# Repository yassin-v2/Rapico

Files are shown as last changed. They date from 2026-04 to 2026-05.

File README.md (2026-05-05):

<picture>
  <source media="(prefers-color-scheme: dark)" srcset="https://github.com/user-attachments/assets/26227bd9-6ad5-4ce1-84e2-db5a73c75b01">
  <source media="(prefers-color-scheme: light)" srcset="https://github.com/user-attachments/assets/26227bd9-6ad5-4ce1-84e2-db5a73c75b01">
  Rapico logo
</picture>

### A RP2040-based development board with a nRF wireless chip, designed in the Raspberry Pi Pico form factor.

----

PCB Render

---

## Features
- **[RP2040](https://pip-assets.raspberrypi.com/categories/814-rp2040/documents/RP-008371-DS-1-rp2040-datasheet.pdf) MCU** - 32bit dual core ARM Cortex M0+ from Raspberry Pi.
- **[nRF24L01P](https://cdn.sparkfun.com/assets/3/d/8/5/1/nRF24L01P_Product_Specification_1_0.pdf) chip** -  2.4GHz radio transceiver, with a PCB trace antenna.
- **USB C** - for programming and power.
- **Raspberry Pi Pico formfactor** - but less pins; 2x18
- **W25Q128JVPIQ flash storage chip** - 16MB high speed flash storage, intergrated with the RP2040 over quad SPI.
- **I2C and SPI** - on many pins.
- **5V and 3.3V power pins**
- Power indicator LED and another addressable LED

## Pinout

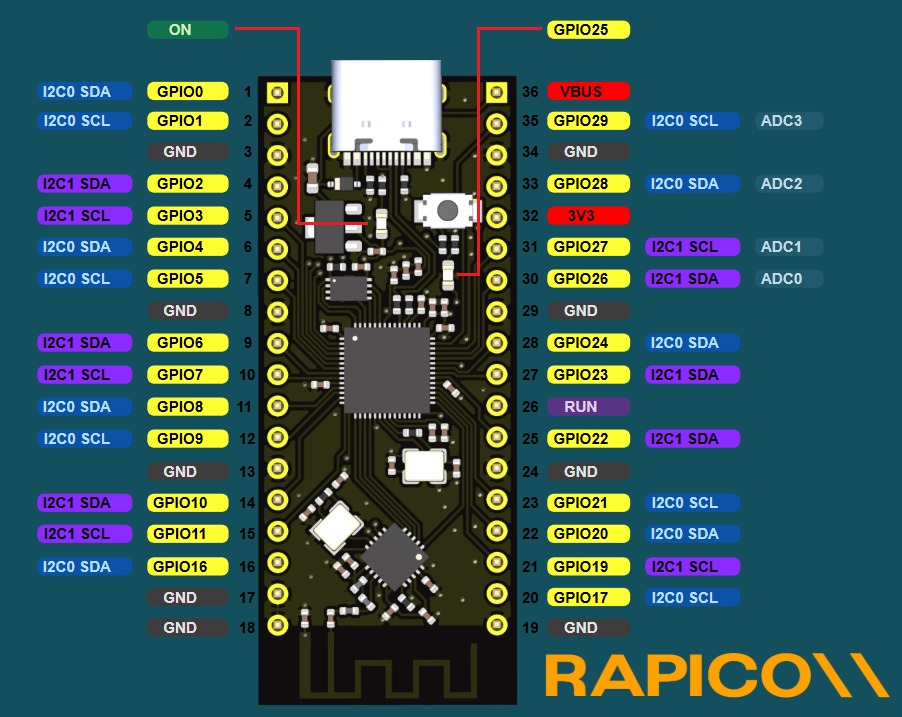
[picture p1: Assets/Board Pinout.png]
PCB Render


## PCB Design
*Find the PCB files [here](https://github.com/yassin-v2/Rapico/tree/main/PCB)*

The PCB is a 2 layer PCB with dimentions 51mm x 21mm.

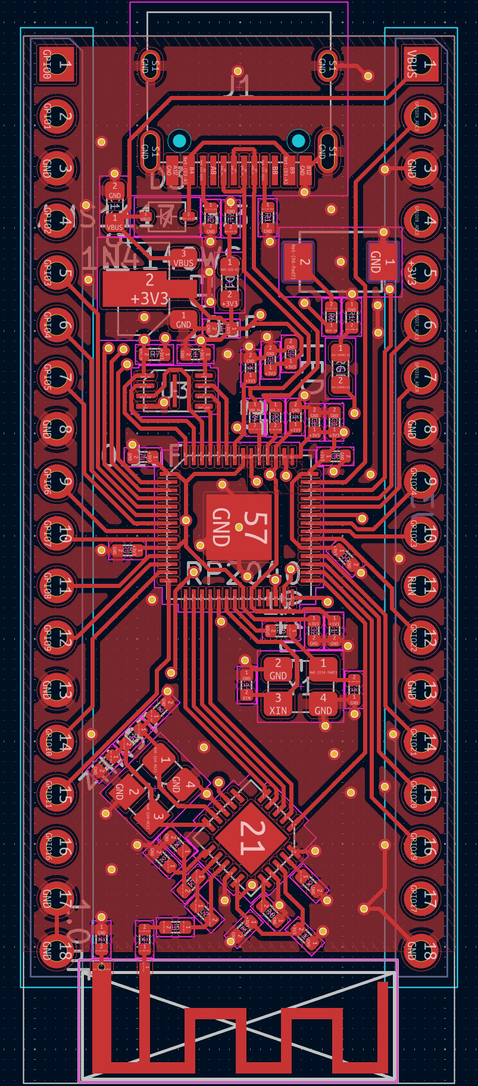
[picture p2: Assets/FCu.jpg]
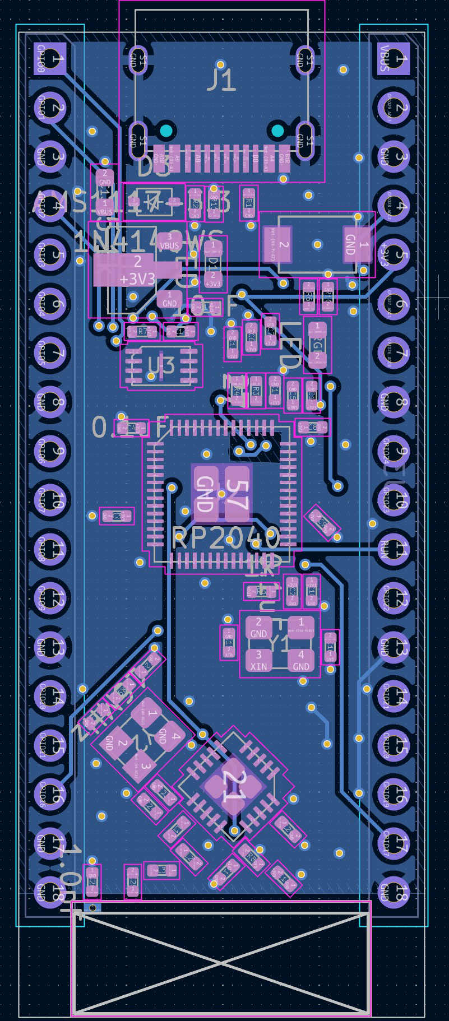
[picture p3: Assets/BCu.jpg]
|  |  |
|:---:|:---:|

## Schematic Design
*Find the schematic files [here](https://github.com/yassin-v2/Rapico/tree/main/PCB)*

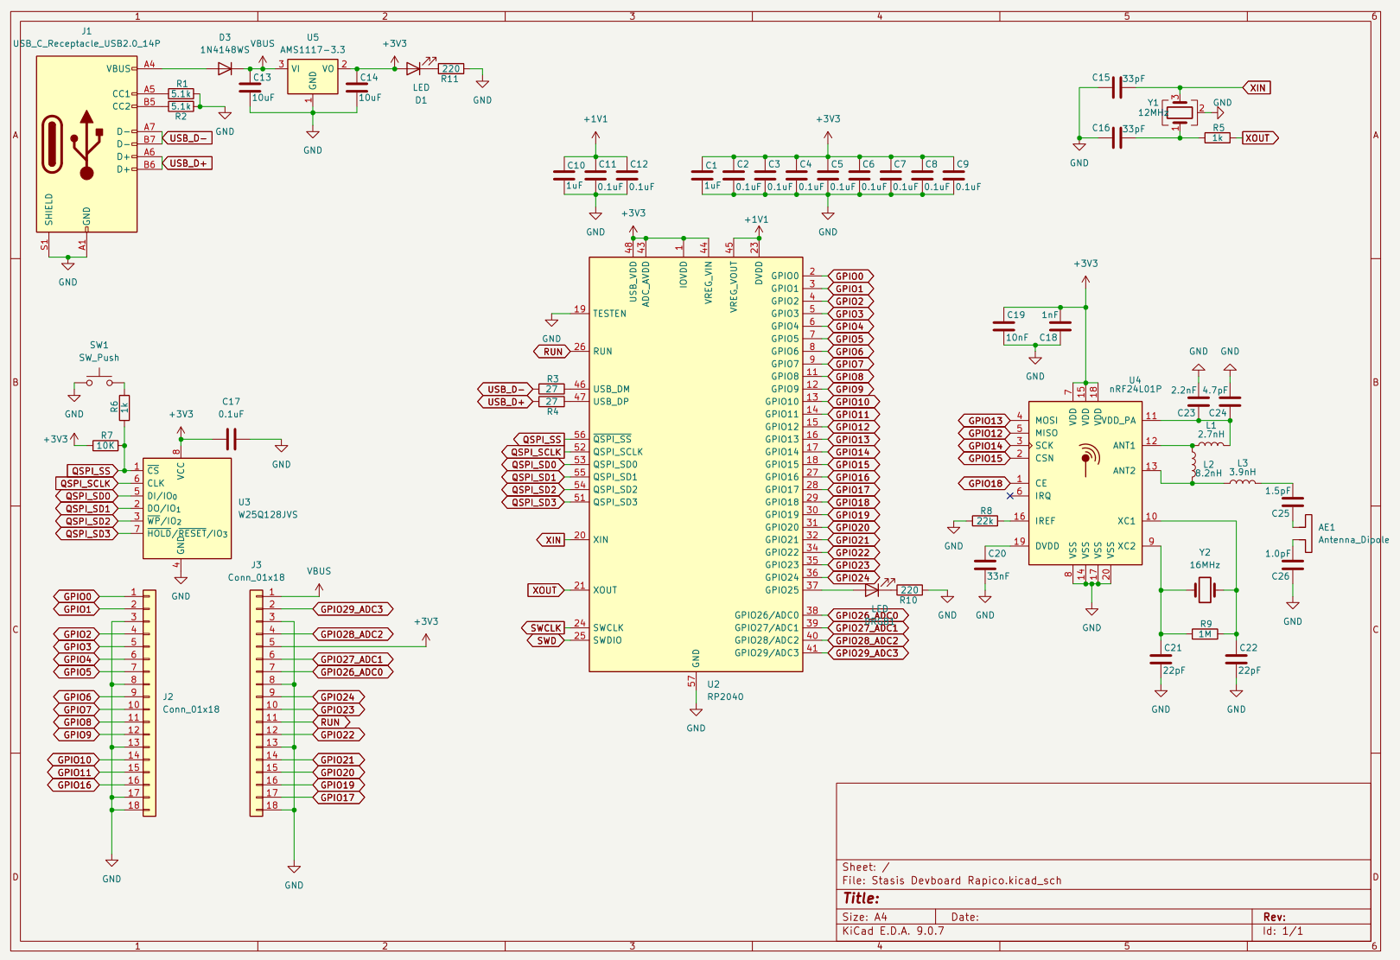
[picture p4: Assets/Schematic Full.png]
  

### nRF chip schematic:
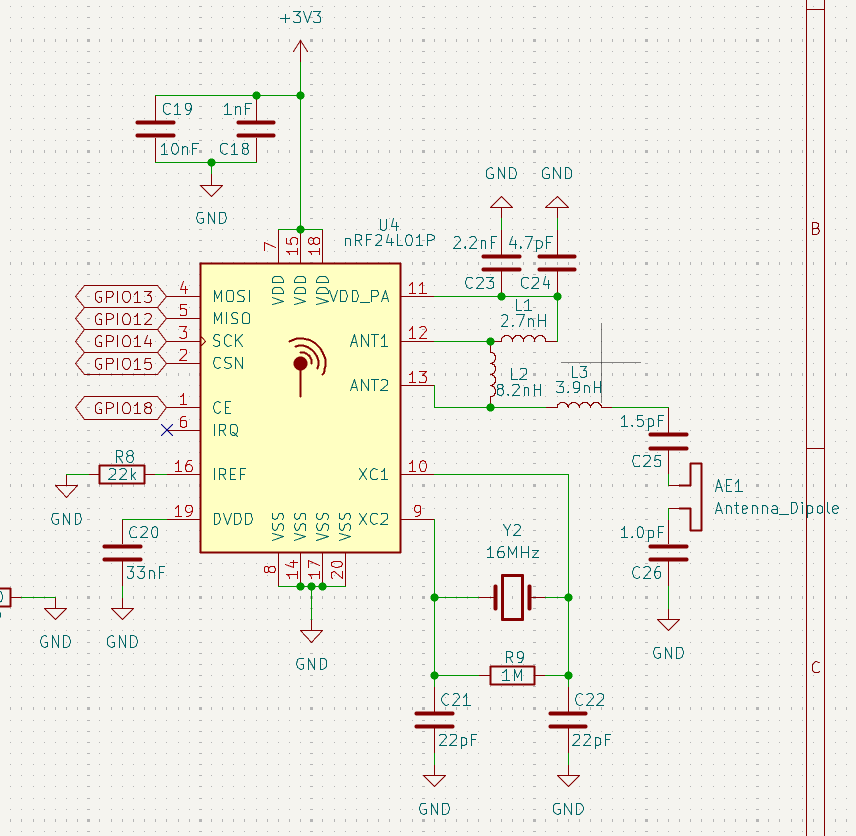
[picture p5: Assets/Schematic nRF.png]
  

### Power input schematic:
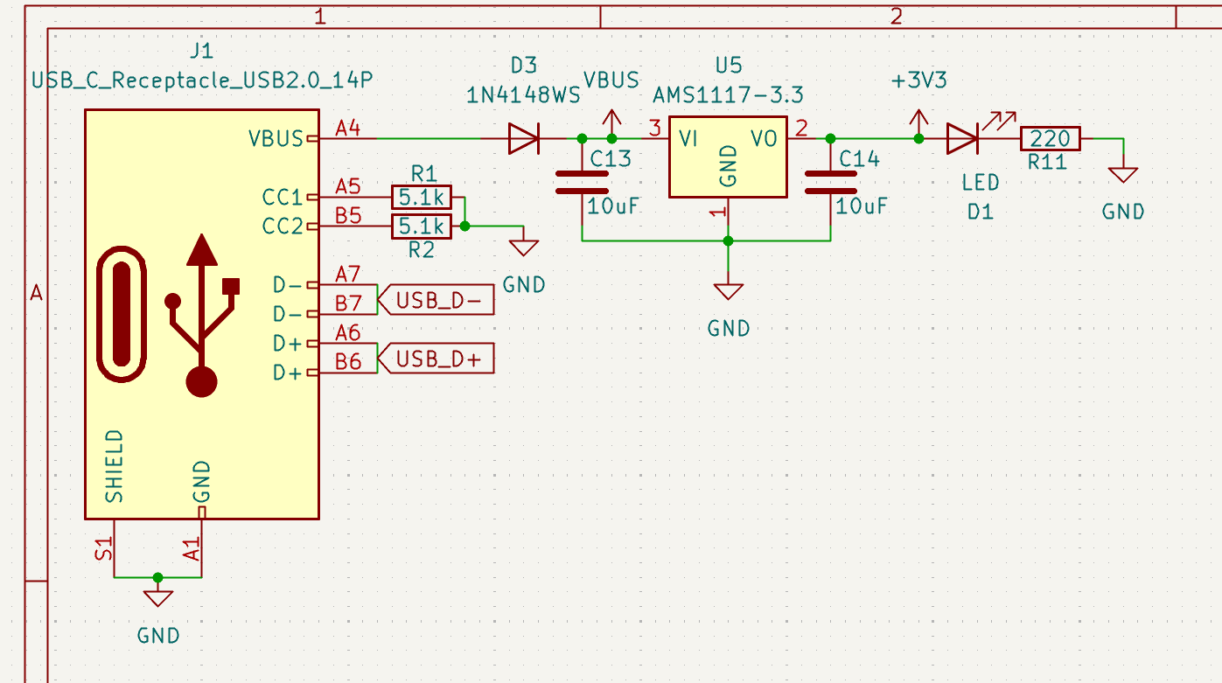
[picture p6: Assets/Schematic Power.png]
  

----
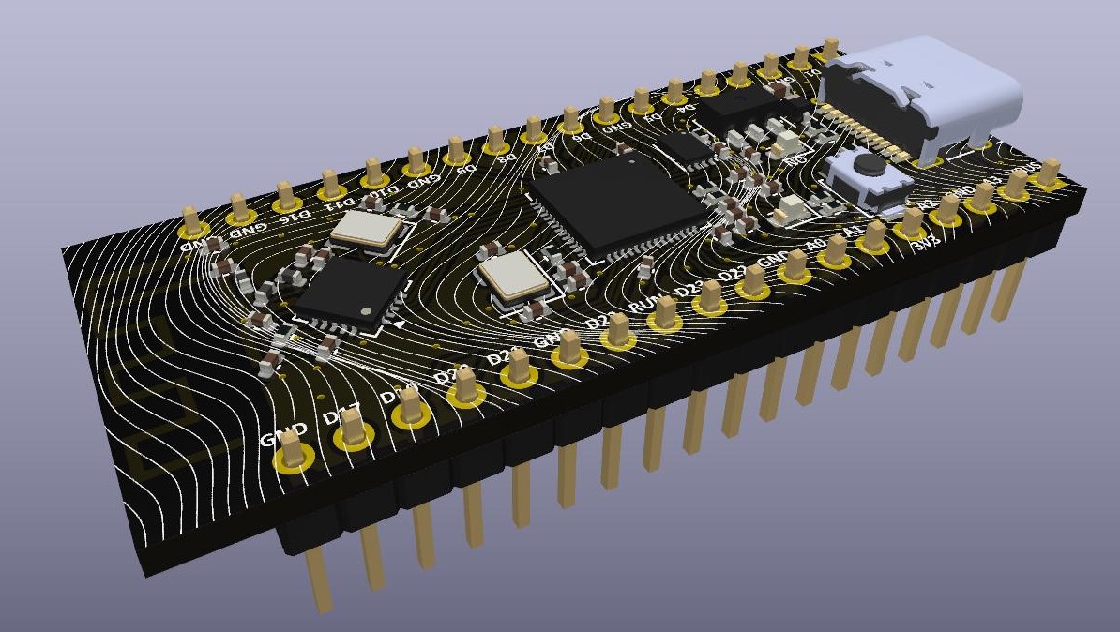
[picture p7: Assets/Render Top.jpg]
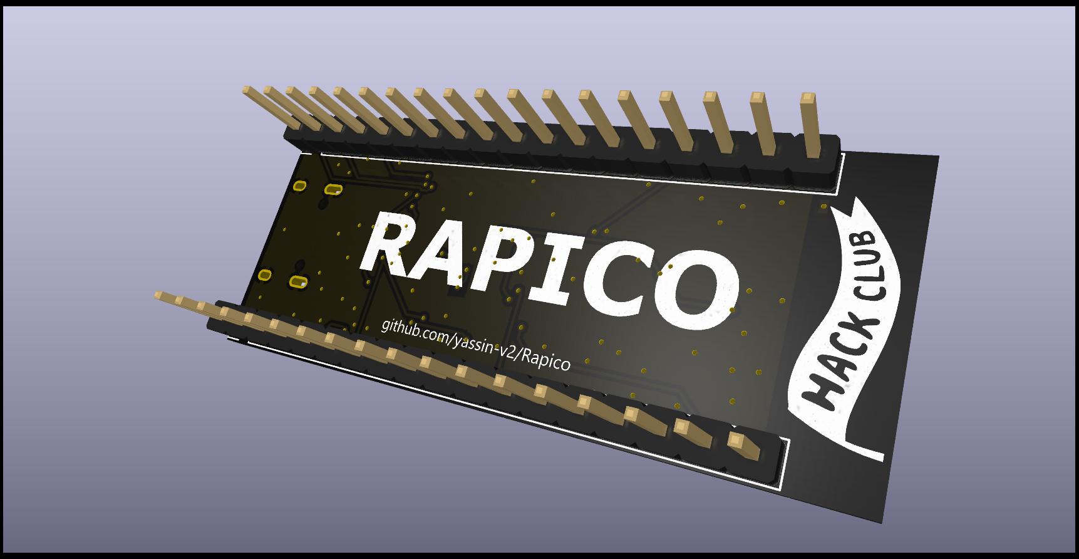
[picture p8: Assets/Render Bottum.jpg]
|  |  |  |
|:---:|:---:|:---:|

<p align="center"><strong><em>Made with KiCad 9, as part of <a href="https://stasis.hackclub.com">Stasis</a> from <a href="https://hackclub.com/">Hackclub</a></em></strong></p>

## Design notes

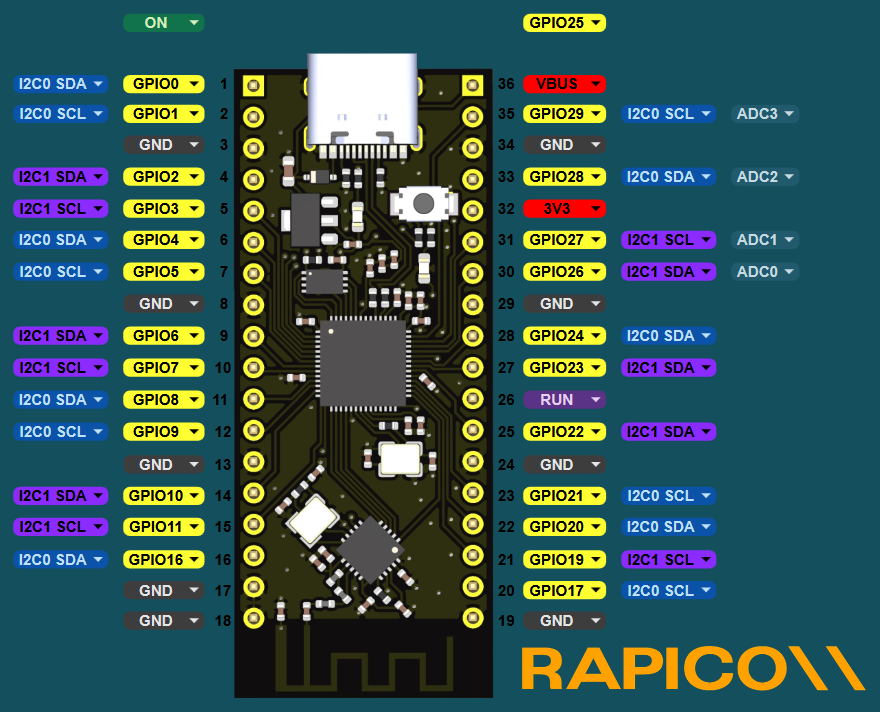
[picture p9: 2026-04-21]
Assets/Board Pinout V2.png

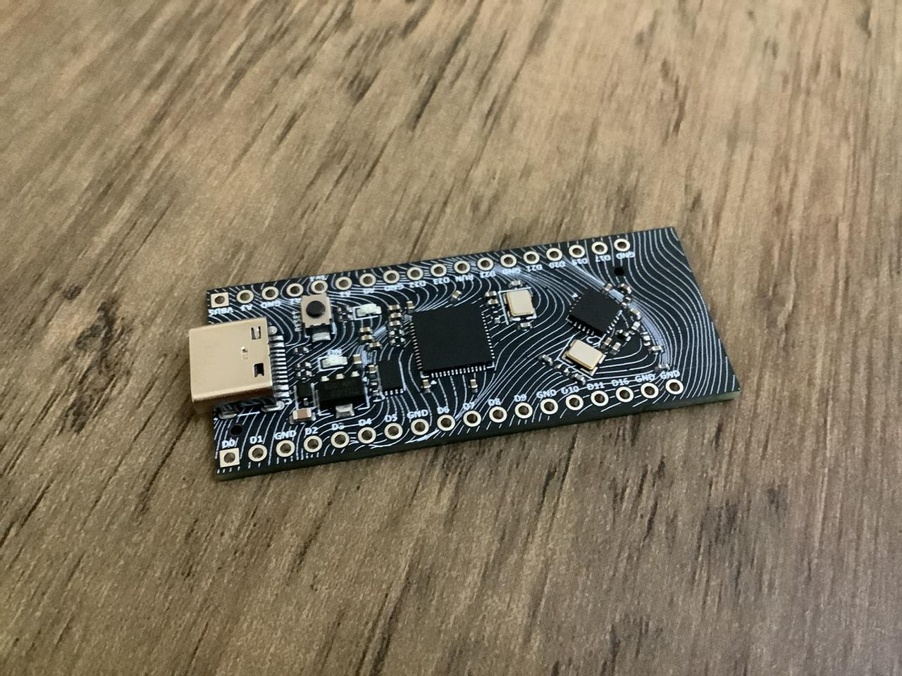
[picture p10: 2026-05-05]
Assets/image.png

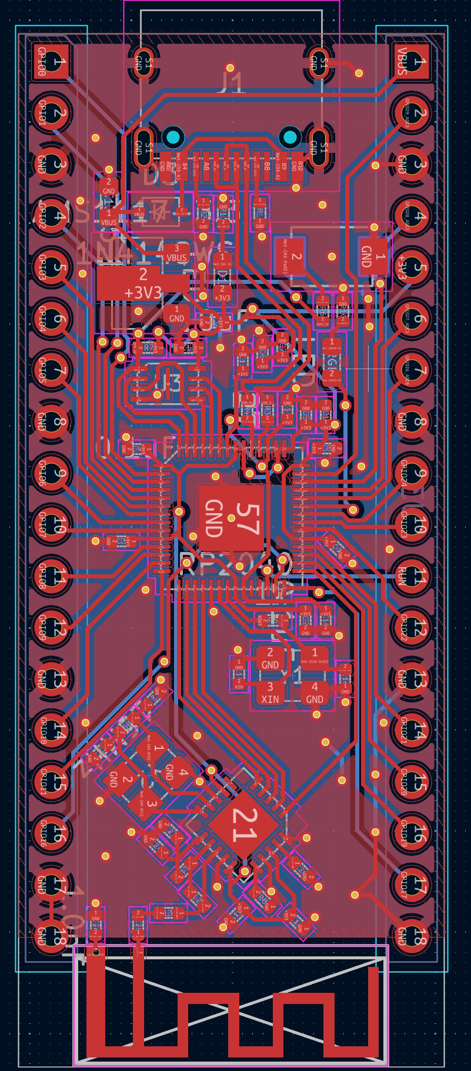
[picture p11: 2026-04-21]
Assets/FCu and BCu.jpg

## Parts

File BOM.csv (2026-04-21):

Comment | Designator | Footprint | JLCPCB Part #
C1,C10 | 1uF | 0402 | C52923
C2,C3 | 0.1uF | 0402 | C307331
C11,C12,C17,C4,C5,C6,C7,C8,C9 | 0.1uF | 0402 | C307331
C13 | 10uF | 0603 | C96446
C14 | 10uF | 0402 | C15525
C15,C16 | 33pF | 0402 | C1562
C18 | 1nF | 0402 | C1523
C19 | 10nF | 0402 | C15195
C20 | 33nF | 0402 | C106862
C21,C22 | 22pF | 0402 | C1555
C23 | 2.2nF | 0402 | C1531
C24 | 4.7pF | 0402 | C1569
C25 | 1.5pF | 0402 | C1552
C26 | 1.0pF | 0402 | C1550
D1,DRGB1 | LED | 0603 | C2286
D3 | 1N4148WS | SOD-323 | C2128
J1 | USB_C_Receptacle_USB2.0_14P | SMD | C165948
L1 | 2.7nH | 0402 | C77108
L2 | 8.2nH | 0402 | C76778
L3 | 3.9nH | 0402 | C76775
R1,R2 | 5.1k | 0402 | C25905
R3,R4 | 27 | 0402 | C25105
R5,R6 | 1k | 0402 | C11702
R7 | 10K | 0402 | C25744
R8 | 22k | 0402 | C25768
R9 | 1M | 0402 | C26083
R10,R11 | 220 | 0402 | C25082
SW1 | SW_Push | SMD,4x3mm | C720477
U2 | RP2040 | LQFN-56(7x7) | C2040
U3 | W25Q128JVS | USON-8-EP(2x3) | C2843335
U4 | nRF24L01P | QFN-20-EP(4x4) | C8791
U5 | AMS1117-3.3 | SOT-89 | C347256
Y1 | 12MHz | SMD3225-4P | C9002
Y2 | 16MHz | SMD3225-4P | C13738

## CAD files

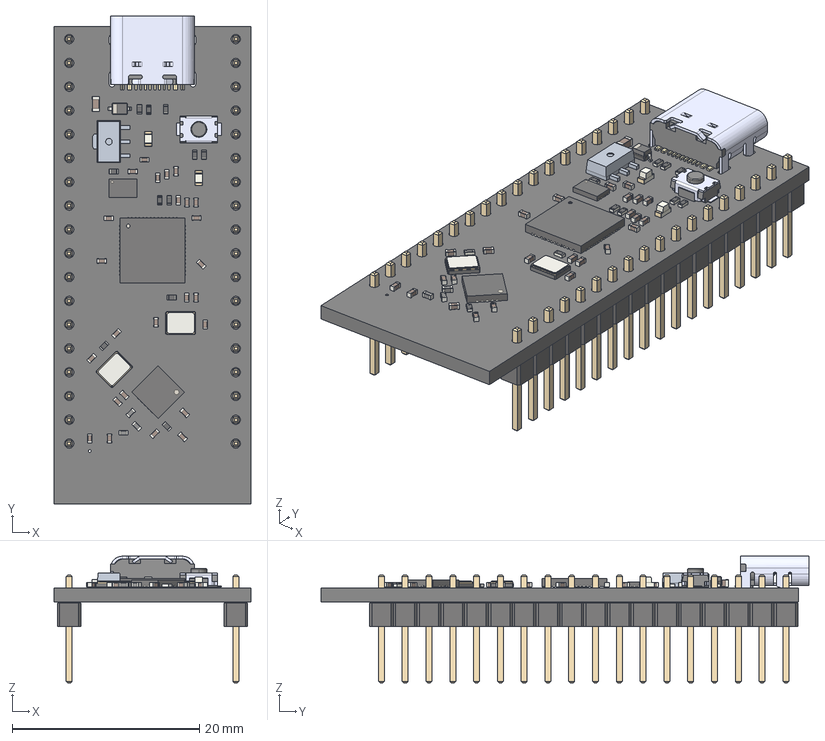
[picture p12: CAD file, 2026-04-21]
PCB/Rapico-Step.step
21.0 x 52.1 x 13.5 mm
Stasis Devboard Rapico 1.1.1
R_0402_1005Metric x 11
C_0603_1608Metric
C_0402_1005Metric x 25
L_0402_1005Metric x 3
QFN-56-1EP_7x7mm_P0.4mm_EP3.2x3.2mm
D_SOD-323
Crystal_SMD_3225-4Pin_3.2x2.5mm x 2
QFN-20-1EP_4x4mm_P0.5mm_EP2.5x2.5mm
Winbond_USON-8-1EP_3x2mm_P0.5mm_EP0.2x1.6mm
LED_0603_1608Metric x 2
TYPE-C-31-M-12
TS-1088-AR02016
PinHeader_1x18_P2.54mm_Vertical x 2
Stasis Devboard Rapico_PCB

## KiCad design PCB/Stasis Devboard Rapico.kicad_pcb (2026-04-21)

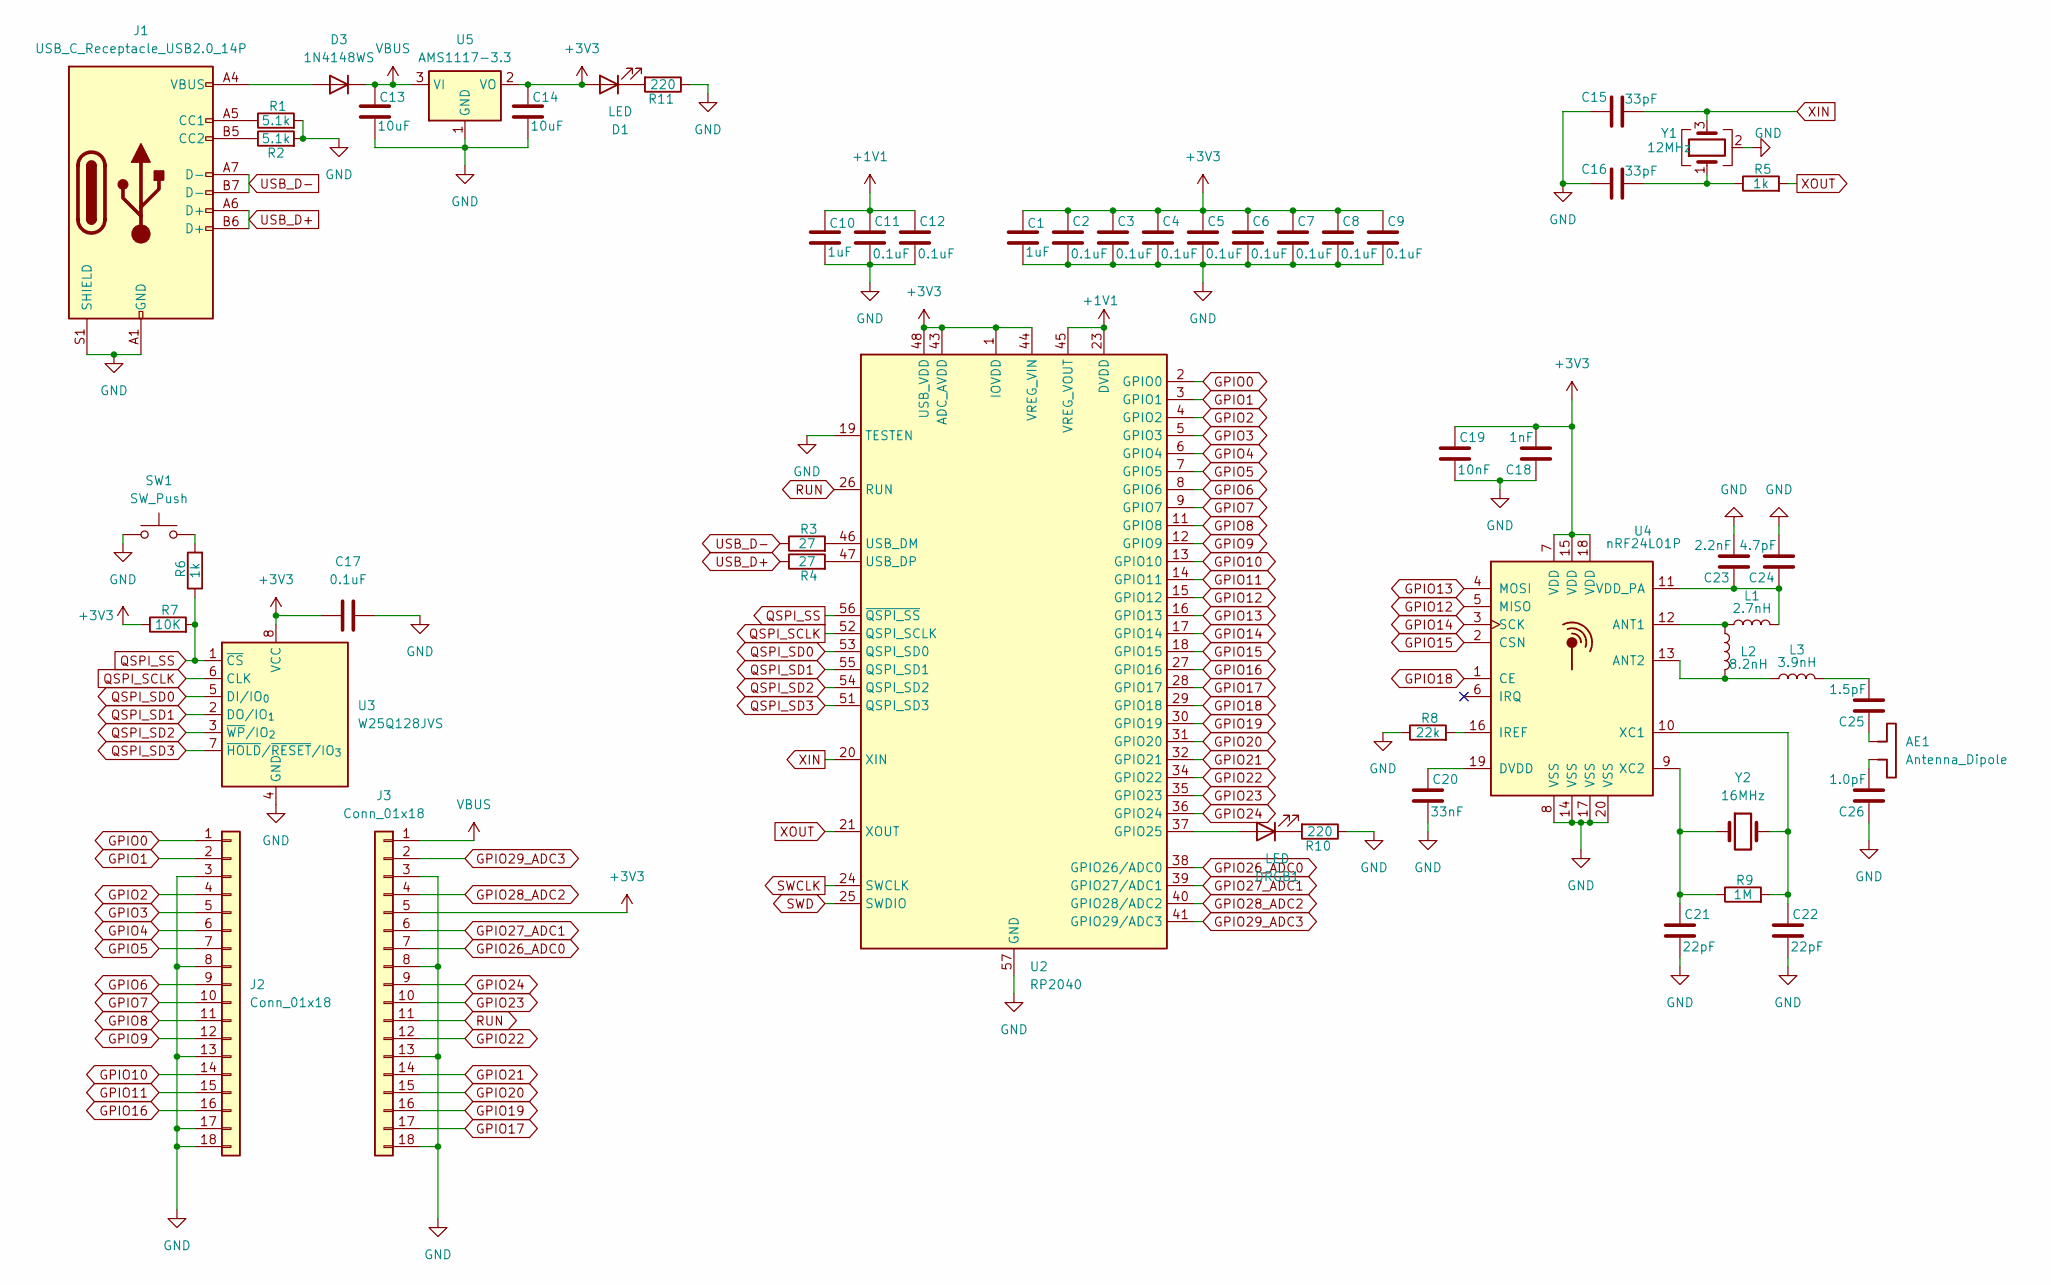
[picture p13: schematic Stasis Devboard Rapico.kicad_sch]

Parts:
AE1: Antenna_Dipole; Texas_SWRA117D_2.4GHz_Left
C1, C10: 1uF; C_0402_1005Metric
C2, C3, C4, C5, C6, C7, C8, C9, C11, C12, C17: 0.1uF; C_0402_1005Metric
C13: 10uF; C_0603_1608Metric
C14: 10uF; C_0402_1005Metric
C15, C16: 33pF; C_0402_1005Metric
C18: 1nF; C_0402_1005Metric
C19: 10nF; C_0402_1005Metric
C20: 33nF; C_0402_1005Metric
C21, C22: 22pF; C_0402_1005Metric
C23: 2.2nF; C_0402_1005Metric
C24: 4.7pF; C_0402_1005Metric
C25: 1.5pF; C_0402_1005Metric
C26: 1.0pF; C_0402_1005Metric
D1: LED; LED_0603_1608Metric
D3: 1N4148WS; D_SOD-323
DRGB1: LED; LED_0603_1608Metric
J1: USB_C_Receptacle_USB2.0_14P; USB_C_Receptacle_HRO_TYPE-C-31-M-12
J2, J3: Conn_01x18; PinHeader_1x18_P2.54mm_Vertical
L1: 2.7nH; L_0402_1005Metric
L2: 8.2nH; L_0402_1005Metric
L3: 3.9nH; L_0402_1005Metric
R1, R2: 5.1k; R_0402_1005Metric
R3, R4: 27; R_0402_1005Metric
R5, R6: 1k; R_0402_1005Metric
R7: 10K; R_0402_1005Metric
R8: 22k; R_0402_1005Metric
R9: 1M; R_0402_1005Metric
R10, R11: 220; R_0402_1005Metric
SW1: SW_Push; SW_TS-1088-AR02016
U2: RP2040; QFN-56-1EP_7x7mm_P0.4mm_EP3.2x3.2mm
U3: W25Q128JVS; Winbond_USON-8-1EP_3x2mm_P0.5mm_EP0.2x1.6mm
U4: nRF24L01P; QFN-20-1EP_4x4mm_P0.5mm_EP2.5x2.5mm
U5: AMS1117-3.3; SOT-89-3
Y1: 12MHz; Crystal_SMD_3225-4Pin_3.2x2.5mm
Y2: 16MHz; Crystal_SMD_3225-4Pin_3.2x2.5mm

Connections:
+1V1: C10.1, C11.1, C12.1, U2.23 (DVDD), U2.45 (VREG_VOUT), U2.50 (DVDD)
+3V3: C1.1, C2.1, C3.1, C4.1, C5.1, C6.1, C7.1, C8.1, C9.1, C14.1, C17.1, C18.2, C19.1, D1.2 (A), J3.5, R7.1, U2.1 (IOVDD), U2.10 (IOVDD), U2.22 (IOVDD), U2.33 (IOVDD), U2.42 (IOVDD), U2.43 (ADC_AVDD), U2.44 (VREG_VIN), U2.48 (USB_VDD), U2.49 (IOVDD), U3.8 (VCC), U4.7 (VDD), U4.15 (VDD), U4.18 (VDD), U5.2 (VO)
GPIO0: J2.1, U2.2 (GPIO0)
GPIO1: J2.2, U2.3 (GPIO1)
GPIO2: J2.4, U2.4 (GPIO2)
GPIO3: J2.5, U2.5 (GPIO3)
GPIO4: J2.6, U2.6 (GPIO4)
GPIO5: J2.7, U2.7 (GPIO5)
GPIO6: J2.9, U2.8 (GPIO6)
GPIO7: J2.10, U2.9 (GPIO7)
GPIO8: J2.11, U2.11 (GPIO8)
GPIO9: J2.12, U2.12 (GPIO9)
GPIO10: J2.14, U2.13 (GPIO10)
GPIO11: J2.15, U2.14 (GPIO11)
GPIO12: U2.15 (GPIO12), U4.5 (MISO)
GPIO13: U2.16 (GPIO13), U4.4 (MOSI)
GPIO14: U2.17 (GPIO14), U4.3 (SCK)
GPIO15: U2.18 (GPIO15), U4.2 (CSN)
GPIO16: J2.16, U2.27 (GPIO16)
GPIO17: J3.17, U2.28 (GPIO17)
GPIO18: U2.29 (GPIO18), U4.1 (CE)
GPIO19: J3.16, U2.30 (GPIO19)
GPIO20: J3.15, U2.31 (GPIO20)
GPIO21: J3.14, U2.32 (GPIO21)
GPIO22: J3.12, U2.34 (GPIO22)
GPIO23: J3.10, U2.35 (GPIO23)
GPIO24: J3.9, U2.36 (GPIO24)
GPIO26_ADC0: J3.7, U2.38 (GPIO26/ADC0)
GPIO27_ADC1: J3.6, U2.39 (GPIO27/ADC1)
GPIO28_ADC2: J3.4, U2.40 (GPIO28/ADC2)
GPIO29_ADC3: J3.2, U2.41 (GPIO29/ADC3)
unnamed: AE1.1, C25.1
unnamed: AE1.2, C26.2
unnamed: C16.2, R5.1, Y1.1
unnamed: C25.2, L3.2
unnamed: D1.1 (K), R11.2
unnamed: D3.2 (A), J1.A4 (VBUS), J1.A9 (VBUS), J1.B4 (VBUS), J1.B9 (VBUS)
unnamed: DRGB1.2 (A), U2.37 (GPIO25)
unnamed: DRGB1.1 (K), R10.2
unnamed: J1.A5 (CC1), R1.1
unnamed: J1.B5 (CC2), R2.1
unnamed: R6.2, SW1.2
unnamed: R3.2, U2.46 (USB_DM)
unnamed: R4.2, U2.47 (USB_DP)
unnamed: L1.1, L2.1, U4.12 (ANT1)
unnamed: L2.2, L3.1, U4.13 (ANT2)
unnamed: C20.1, U4.19 (DVDD)
unnamed: R8.2, U4.16 (IREF)
unnamed: C23.1, C24.1, L1.2, U4.11 (VDD_PA)
unnamed: C21.1, R9.1, U4.9 (XC2), Y2.1
QSPI_SCLK: U2.52 (QSPI_SCLK), U3.6 (CLK)
QSPI_SD0: U2.53 (QSPI_SD0), U3.5 (DI/IO_{0})
QSPI_SD1: U2.55 (QSPI_SD1), U3.2 (DO/IO_{1})
QSPI_SD2: U2.54 (QSPI_SD2), U3.3 (~WP/IO_{2})
QSPI_SD3: U2.51 (QSPI_SD3), U3.7 (~HOLD/~RESET/IO_{3})
QSPI_SS: R6.1, R7.2, U2.56 (~QSPI_SS), U3.1 (~CS)
RUN: J3.11, U2.26 (RUN)
SWCLK: U2.24 (SWCLK)
SWD: U2.25 (SWDIO)
USB_D+: J1.A6 (D+), J1.B6 (D+), R4.1
USB_D-: J1.A7 (D-), J1.B7 (D-), R3.1
VBUS: C13.1, D3.1 (K), J3.1, U5.3 (VI)
XIN: C15.2, U2.20 (XIN), Y1.3
XOUT: R5.2, U2.21 (XOUT)

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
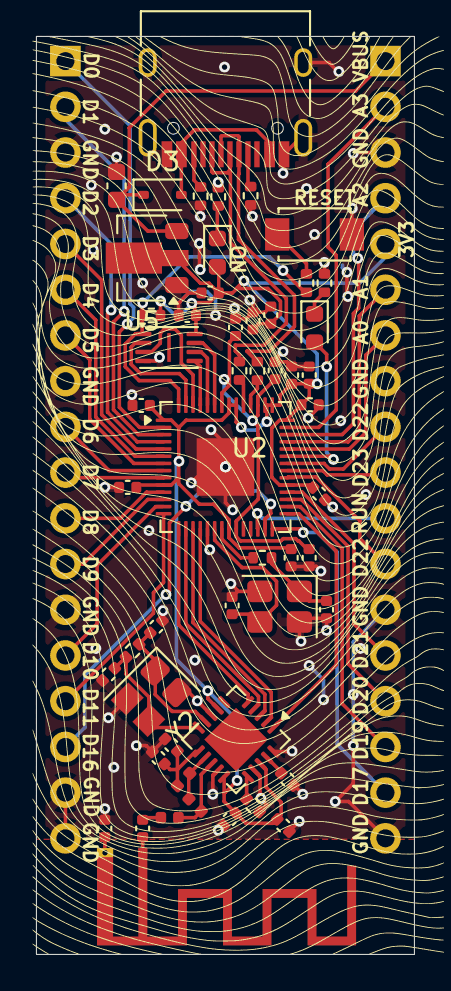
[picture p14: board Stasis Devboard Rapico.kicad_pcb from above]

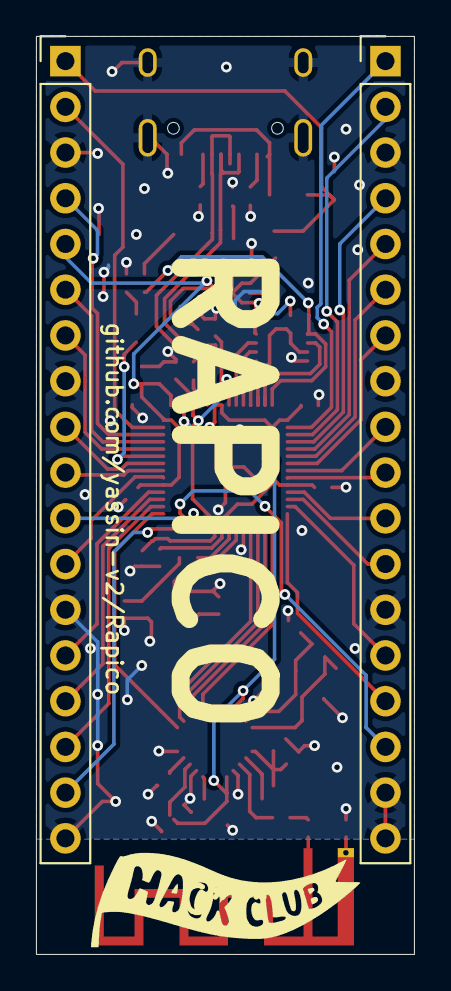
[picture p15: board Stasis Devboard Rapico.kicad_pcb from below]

Board: 2 copper layers, 21.0 x 51.0 mm, 54 parts (2 on the bottom side), 64 nets.

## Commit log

2026-04-21 Adding PCB and images
    [Rapico-BOM.csv, Stasis Devboard Rapico.kicad_pcb, Stasis Devboard Rapico.kicad_sch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]
2026-04-21 Higher res PCB images
2026-04-21 Added board pinout image
2026-04-21 Board pinout v2
2026-04-21 Added .step file
    [Rapico-Step.step]
